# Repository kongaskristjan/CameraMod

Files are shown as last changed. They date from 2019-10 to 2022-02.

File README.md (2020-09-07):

# CameraMod

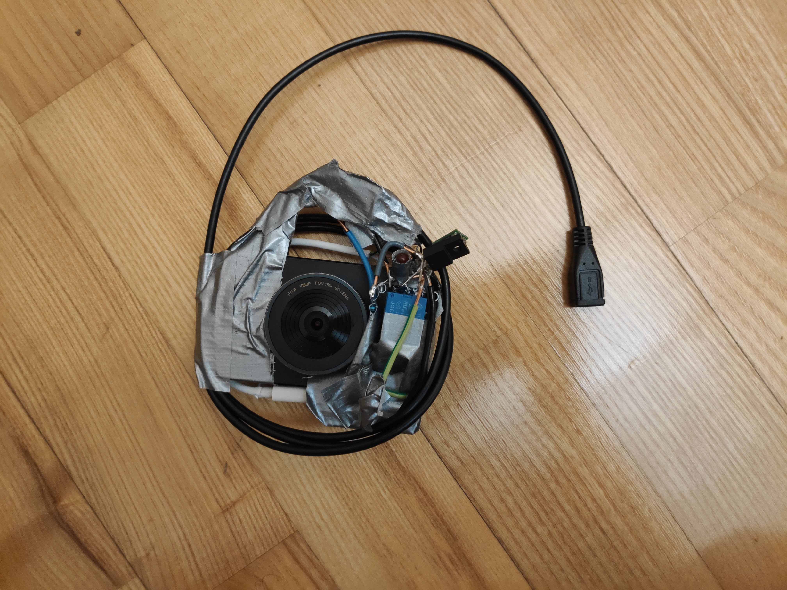
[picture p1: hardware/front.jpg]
Front side of the camera


I bought a XIAOMI Mijia 160° dash cam for my car, but soon it became clear that there is an issue.
The camera should start recording once car starts supplying USB power,
but sometimes (perhaps ~10% chance) the camera would fail to do so.
I've also failed to reproduce this indoors (it could be temperature dependent),
so warranty repair was unlikely to help. So I decided to solve this problem myself.

Specifically, two factors made this tractable:
* An LED indicates whether the device is recording (white) or not (red)
* A failure to record can be solved with a simple restart (cut the power for a few seconds)

The LED is read using a covered photoresistor with a blue light filter and an analog to digital converter (built into Arduino).
The power is handled with a transistor+relay.

The final electrical scheme was complicated by two main factors:
* The 5V USB supply became 4.5V when the camera was on, which rendered the Arduino unstable.
Thus, Arduino power had to be regulated.
* Arduino power has to be swappable. While debugging, it's connected and powered using the computer's USB.
While working in the car, it's powered by the same 5V that goes to the camera. These two power sources
must not be connected, otherwise I risk damaging my computer. As a result I had to cut and solder a few USB cables.

Schema

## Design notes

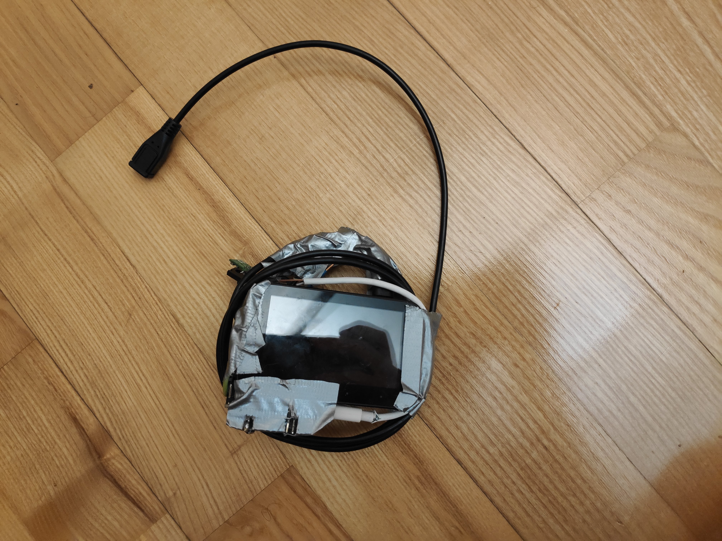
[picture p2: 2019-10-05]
hardware/back.jpg

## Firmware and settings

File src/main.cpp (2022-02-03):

#include <cstdio> // We're running short on memory, use printf instead of cout (program must be loaded to ram to enable flash)
#include <vector>
#include "pico/stdlib.h"
#include "hardware/gpio.h"
#include "hardware/adc.h"
#include "hardware/pio.h"
#include "hardware/clocks.h"
#include "ws2812.pio.h"
#include "hardware/flash.h"

constexpr bool resetCounts = false;

constexpr int sleepLength = 50; // ms
constexpr int totalIters = 15 /* seconds */ * (1000 /* ms per s */ / sleepLength);
constexpr int stabIters1 = 5, stabIters2 = 2;
constexpr int minMeasurementTimeDiff = 15;
constexpr int minDelta = 56;

int adcValues[totalIters];

const int adcPin = 28, cameraPin = 0; // Voltage pin = A2=D2, cameraPin = D6
const int pixelPwrPin = 11, pixelPin = 12;
const int adcOffset = 26;

class NeoPixel {
private:
    pio_hw_t *pio;
    uint offset;

public:
    explicit NeoPixel(pio_hw_t *pio): pio(pio) {
        offset = pio_add_program(pio, &ws2812_program);
        ws2812_program_init(pio, 0, offset, pixelPin, 800000, true);
    }

    ~NeoPixel() {
        write(0, 0, 0);
        pio_remove_program(pio, &ws2812_program, offset);
    }

    void write(uint8_t r, uint8_t g, uint8_t b) {
        uint32_t grb_ = ((uint32_t) r << 16) | ((uint32_t) g << 24) | ((uint32_t) b << 8);
        pio_sm_put_blocking(pio0, 0, grb_);
        sleep_ms(1); // 100 us is enough
    }

    void show_ms(uint32_t ms, uint8_t r, uint8_t g, uint8_t b) {
        write(r, g, b);
        sleep_ms(ms);
        write(0, 0, 0);
    }

    void blink_number(uint32_t number, uint8_t brightness) {
        bool showing = false;
        printf("Showing %d\n", number);
        sleep_ms(500);
        for(uint32_t bit = 1u << 31; bit; bit >>= 1) {
            if(number & bit)
                showing = true;

            if(showing) {
                if(number & bit)
                    show_ms(1000, 0, brightness, 0);
                else
                    show_ms(1000, brightness, 0, 0);
                show_ms(200, 0, 0, 0);
            }
        }
        sleep_ms(500);
    }
};

struct Counts {
    int successes = 0;
    int fails = 0;
    static constexpr int addr = 256 * 1024; // Multiple of 4096

    void read() {
        successes = * (const int *) (XIP_BASE + addr);
        fails = * (const int *) (XIP_BASE + addr + 4);
    }

    void write() {
        int data[FLASH_PAGE_SIZE/4];
        data[0] = successes;
        data[1] = fails;

        flash_range_erase(addr, FLASH_SECTOR_SIZE);
        flash_range_program(addr, (uint8_t *) data, FLASH_PAGE_SIZE);
    }
};


struct Step {
    int iter = 0;
    int delta = 0;
};

void reset() {
    printf("Switching camera off\n");
    gpio_put(cameraPin, false);
    sleep_ms(10000);
    printf("Switching camera on\n");
    gpio_put(cameraPin, true);
}

Step findMaxStep(int startIter, int stabIters) {
    Step best;
    for (int i = startIter; i < totalIters - stabIters; ++i) {
        int delta = adcValues[i + stabIters] - adcValues[i];
        if (delta < best.delta) {
            best.iter = i;
            best.delta = delta;
        }
    }
    return best;
}

bool isCameraRunning() {
    Step s1 = findMaxStep(0, stabIters1);
    printf("1. step: iter: %d,\t delta: %d\n", s1.iter, s1.delta);
    Step s2 = findMaxStep(s1.iter + minMeasurementTimeDiff, stabIters2);
    printf("2. step: iter: %d,\t delta: %d\n", s2.iter, s2.delta);
    if (s2.delta < -minDelta) {
        printf("Camera success\n");
        return true;
    }
    printf("Camera fail\n");
    return false;
}

void init() {
    stdio_init_all();

    gpio_init(pixelPwrPin);
    gpio_set_dir(pixelPwrPin, GPIO_OUT);
    gpio_put(pixelPwrPin, true);
    sleep_ms(1200);
    printf("\n\nStarting microcontroller\n");

    adc_init();
    adc_select_input(adcPin - adcOffset);
    gpio_init(cameraPin);
    gpio_set_dir(cameraPin, GPIO_OUT);
    gpio_put(cameraPin, true);
}

bool experimentCameraRunning() {
    for (int i = 0; i < totalIters; ++i) {
        int adcValue = adc_read();
        adcValues[i] = adcValue;
        sleep_ms(sleepLength);
        printf("ADC value: %d         (iteration %d)\n", adcValue, i);
    }
    return isCameraRunning();
}

void loop() {
    while(true) {
    }
}

void printSuccessesFails() {
    Counts counts;
    counts.read();
    printf("successes: %d  fails: %d\n", counts.successes, counts.fails);
}

void displaySuccessesFails(NeoPixel neo) {
    Counts counts;
    counts.read();

    int brightness = 8;
    neo.show_ms(2000, 0, 0, brightness);
    neo.blink_number(counts.successes, brightness);
    neo.show_ms(2000, 0, 0, brightness);
    neo.blink_number(counts.fails, brightness);
    neo.show_ms(2000, 0, 0, brightness);
}

int main() {
    init();
    NeoPixel neo(pio0);

    if(resetCounts) {
        Counts counts;
        counts.write();
        printf("Resetting success/fail counts\n");
        loop();
    }

    Counts counts;
    counts.read();
    printSuccessesFails();

    while(! experimentCameraRunning()) {
        ++counts.fails;
        counts.write();
        printf("Camera start failed: resetting\n");
        printSuccessesFails();

        neo.write(20, 0, 0);
        reset();
        neo.write(0, 0, 0);
    }

    ++counts.successes;
    counts.write();
    printf("Camera start successful: looping forever\n");
    printSuccessesFails();
    displaySuccessesFails(neo);

    loop();
    return 0;
}

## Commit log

2019-09-23 Add reading light sensor
2019-09-24 Add switching relay
2019-09-24 Add automatic camera switching based on light sensor readings
2019-09-27 Add camera initially on message
2019-09-28 Add logging to EEPROM and log printing
2021-01-27 Simplify wiring
2021-01-27 Add camera detection mechanism, additional logging
2021-01-29 Switch to normal mode
2021-01-29 Rename arduino directory to src
2022-01-28 Add custom pcb layout
    [Camera.kicad_sch, Camera.sch]
2022-01-30 Rewrite Arduino code as C++ (with RP2040 calls)
2022-01-30 Fix transistor orientation
    [Camera.kicad_sch]
2022-01-30 Update minDelta for RP2040 ADC
2022-02-03 Set resetCounts to false
    [main.cpp]
2022-02-03 Show number of successes/fails with neopixel
    [main.cpp]
